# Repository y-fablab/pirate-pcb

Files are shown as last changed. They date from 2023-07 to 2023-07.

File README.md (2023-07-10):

# pirate-pcb

PCB for Pirate Box

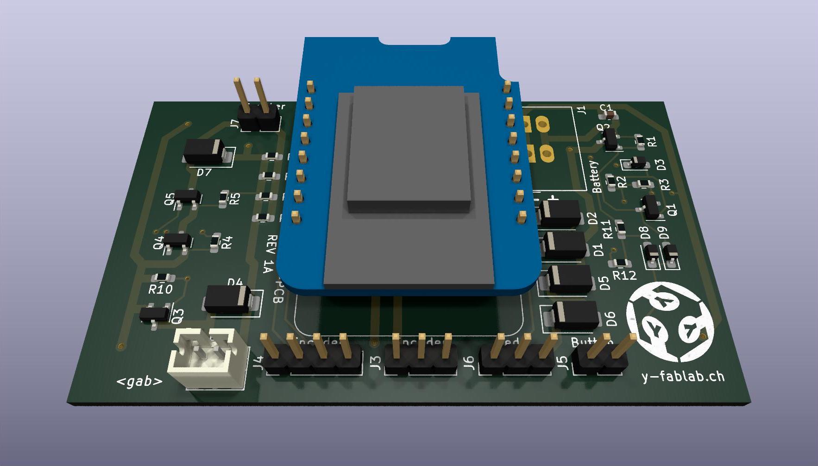
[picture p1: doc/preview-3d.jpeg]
Preview


## Documentation

* [Schematics](./doc/schematics.pdf)
* [2D Preview](./doc/preview-2d.jpeg)

## Warnings

The WEMOS/LOLIN D1 mini is directly powered by the battery. We typically use 4 AA batteries. Therefore, the power voltage is 6V instead of the 5V usually required. This does not cause any problem, provided that:

1. On the D1 mini, this voltage only powers the 3.3V regulator. This is the case for classic versions of D1 mini where both the CH340 and the SPI memory are powered by 3.3V.
2. When powered through USB, the power goes through a diode. This is the case for all D1 mini versions up to 3.x.x. However, on version 4.0.0, there is no diode and the 6V battery would be connected directly to the USB 5V line, which is not good. Do not use D1 mini version 4.0.0+ on this board.

We recommend using D1 mini v3.x.x and verifying that it has a CH340 chip.

## License

Copyright (c) 2023 [y-fablab.ch](https://www.y-fablab.ch)

Licensed under the [Creative Commons CC-BY 4.0 License](https://creativecommons.org/licenses/by/4.0/)

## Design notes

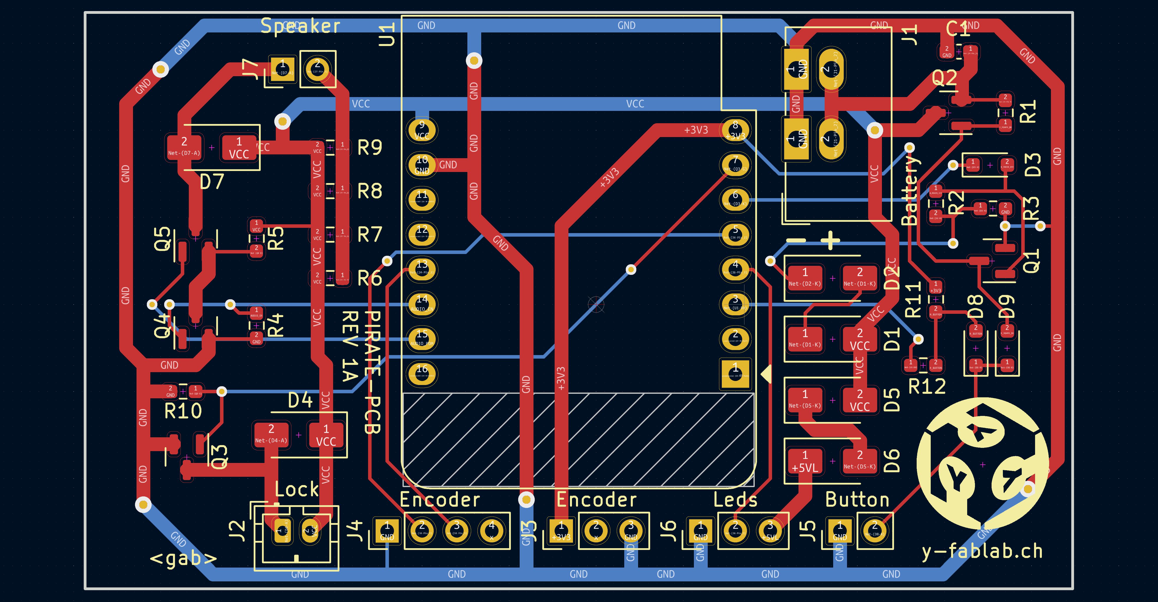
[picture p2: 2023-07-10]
doc/preview-2d.jpeg

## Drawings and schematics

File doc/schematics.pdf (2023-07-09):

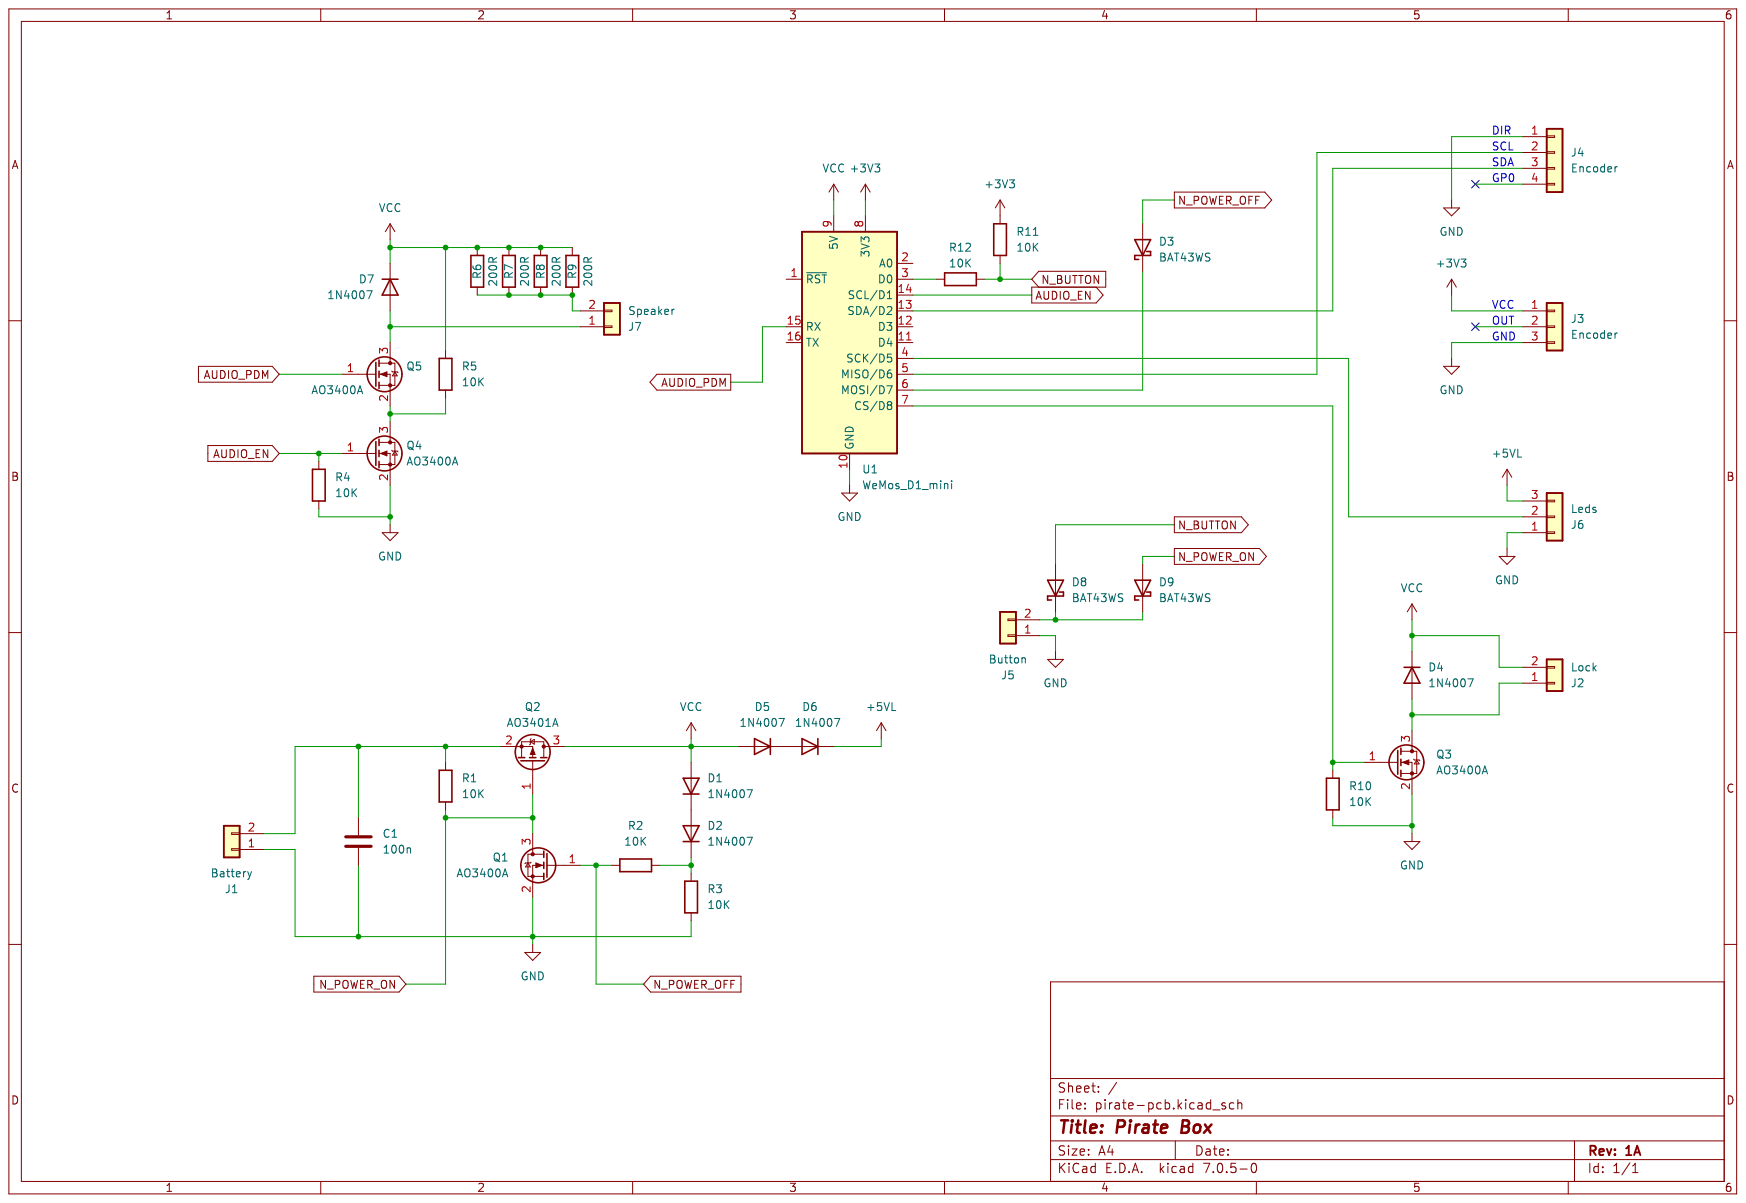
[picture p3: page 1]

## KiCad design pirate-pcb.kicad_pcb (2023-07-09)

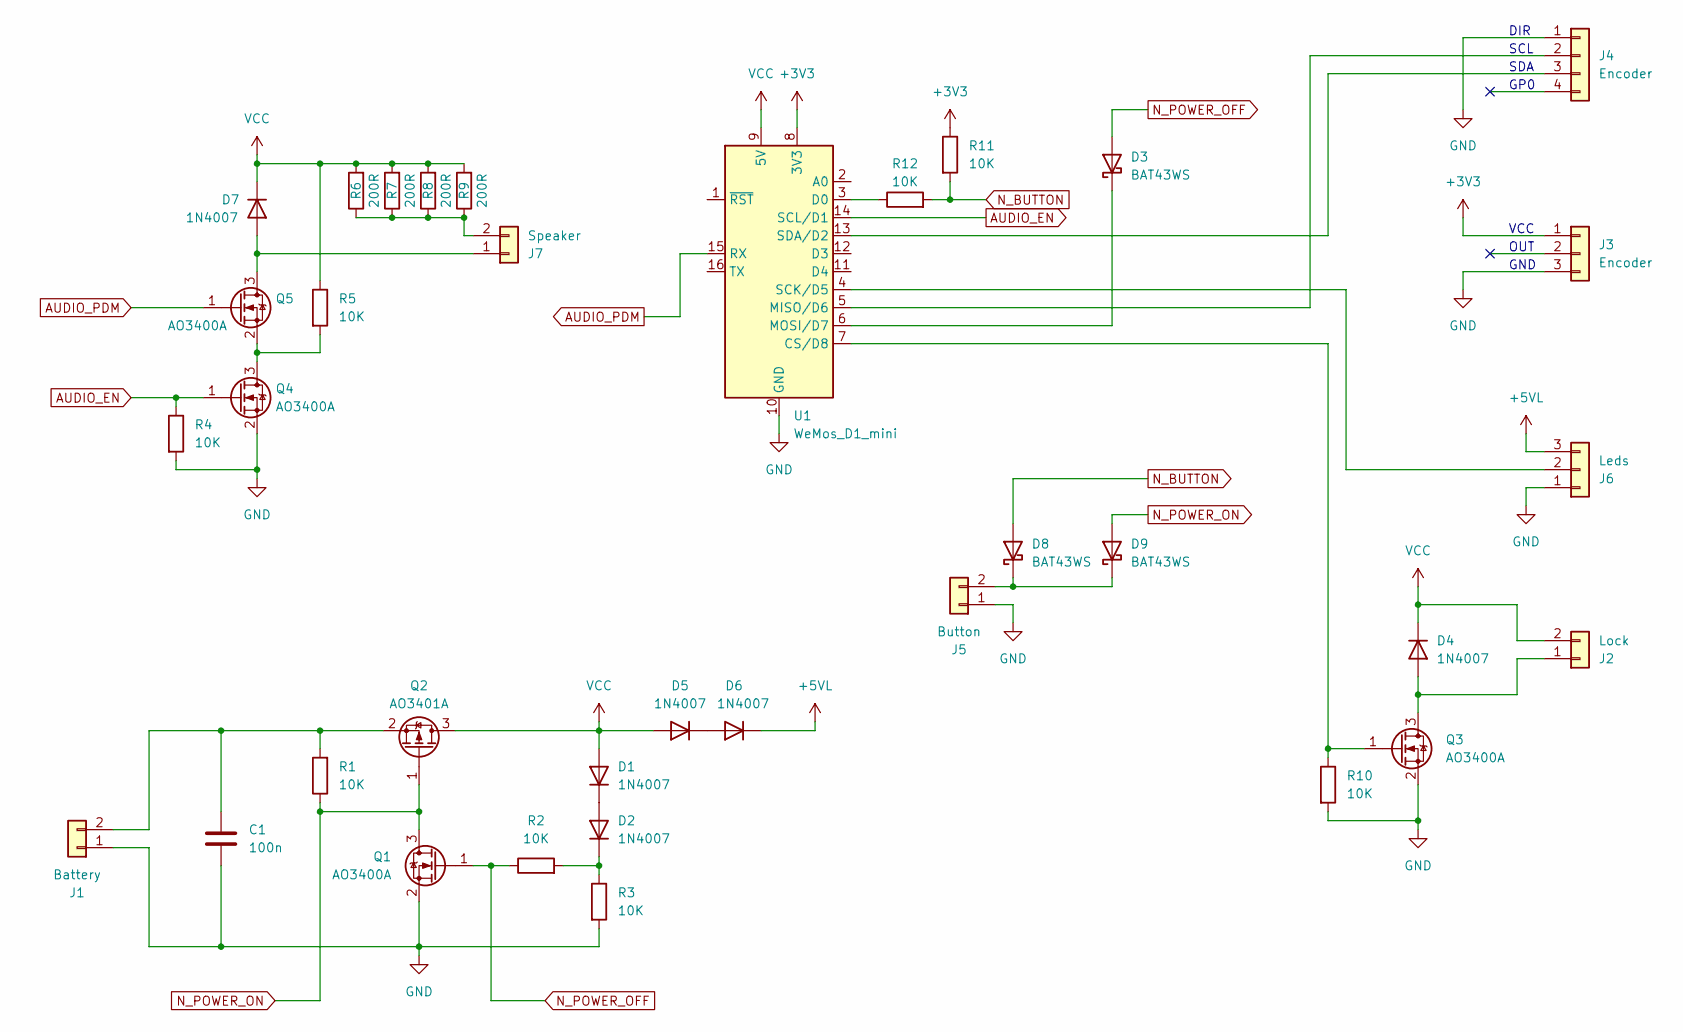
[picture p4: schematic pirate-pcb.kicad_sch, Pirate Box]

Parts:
C1: 100n; C_0603_1608Metric_Pad1.08x0.95mm_HandSolder
D1, D2, D4, D5, D6, D7: 1N4007; D_SMA
D3, D8, D9: BAT43WS; D_SOD-323_HandSoldering
J1: Battery; TerminalBlock_KaiFeng_KF141R-2_1x02_P2.54mm
J2: Lock; JST_PH_B2B-PH-K_1x02_P2.00mm_Vertical
J3: Encoder; PinHeader_1x03_P2.54mm_Vertical
J4: Encoder; PinHeader_1x04_P2.54mm_Vertical
J5: Button; PinHeader_1x02_P2.54mm_Vertical
J6: Leds; PinHeader_1x03_P2.54mm_Vertical
J7: Speaker; PinHeader_1x02_P2.54mm_Vertical
Q1, Q3, Q4, Q5: AO3400A; SOT-23
Q2: AO3401A; SOT-23
R1, R2, R3, R4, R5, R10, R11, R12: 10K; R_0603_1608Metric_Pad0.98x0.95mm_HandSolder
R6, R7, R8, R9: 200R; R_0603_1608Metric_Pad0.98x0.95mm_HandSolder
U1: WeMos_D1_mini; WEMOS_D1_mini_light

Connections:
+3V3: J3.1, R11.1, U1.8 (3V3)
+5VL: D6.1 (K), J6.3
AUDIO_EN: Q4.1 (G), R4.1, U1.14 (SCL/D1)
AUDIO_PDM: Q5.1 (G), U1.15 (RX)
GND: C1.2, J1.1, J3.3, J4.1, J5.1, J6.1, Q1.2 (S), Q3.2 (S), Q4.2 (S), R3.2, R4.2, R10.2, U1.10 (GND)
N_BUTTON: D8.2 (A), R11.2, R12.2
N_POWER_OFF: D3.2 (A), Q1.1 (G), R2.1
N_POWER_ON: D9.2 (A), Q1.3 (D), Q2.1 (G), R1.1
unnamed: D1.1 (K), D2.2 (A)
unnamed: D2.1 (K), R2.2, R3.1
unnamed: D3.1 (K), U1.6 (MOSI/D7)
unnamed: D4.2 (A), J2.1, Q3.3 (D)
unnamed: D5.1 (K), D6.2 (A)
unnamed: D7.2 (A), J7.1, Q5.3 (D)
unnamed: D8.1 (K), D9.1 (K), J5.2
unnamed: C1.1, J1.2, Q2.2 (S), R1.2
unnamed: J4.2, U1.5 (MISO/D6)
unnamed: J4.3, U1.13 (SDA/D2)
unnamed: J6.2, U1.4 (SCK/D5)
unnamed: J7.2, R6.1, R7.1, R8.1, R9.1
unnamed: Q3.1 (G), R10.1, U1.7 (CS/D8)
unnamed: Q4.3 (D), Q5.2 (S), R5.2
unnamed: R12.1, U1.3 (D0)
VCC: D1.2 (A), D4.1 (K), D5.2 (A), D7.1 (K), J2.2, Q2.3 (D), R5.1, R6.2, R7.2, R8.2, R9.2, U1.9 (5V)

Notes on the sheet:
OUT
GND
DIR
GP0
SDA
VCC
SCL

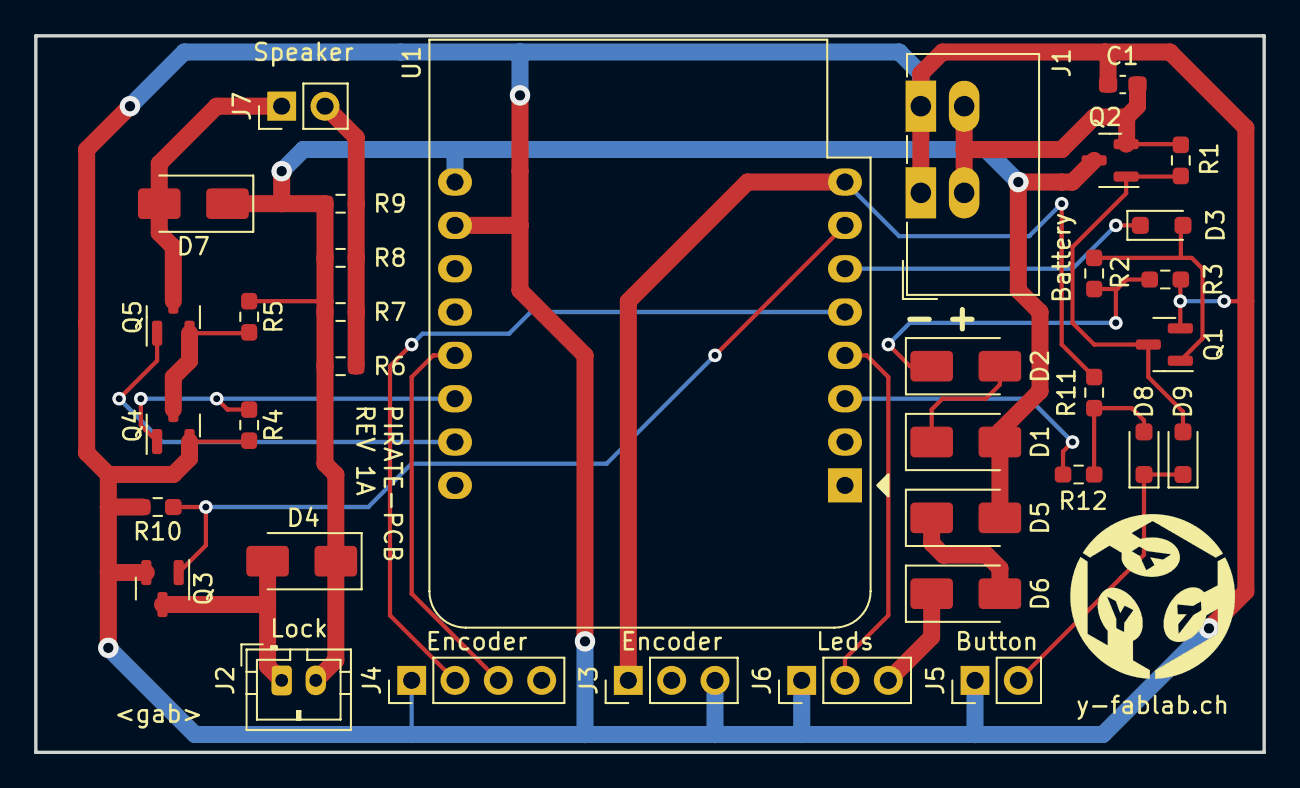
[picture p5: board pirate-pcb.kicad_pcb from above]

Board: 2 copper layers, 72.0 x 42.0 mm, 36 parts (0 on the bottom side), 24 nets.

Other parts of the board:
G1: LOGO; y-fablab_logo_10mm

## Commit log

2023-07-09 revision 1A
    [pirate-pcb.kicad_pcb, pirate-pcb.kicad_sch]
2023-07-09 add prod files
    [pirate-pcb-B_Cu.gbr, pirate-pcb-B_Mask.gbr, pirate-pcb-B_Paste.gbr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]
